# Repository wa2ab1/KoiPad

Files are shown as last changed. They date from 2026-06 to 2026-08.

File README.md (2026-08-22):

# KoiPad: External Numpad Companion with Rotary Encoder

KoiPad is an external numpad companion with a large rotary encoder, designed for a fun desk setup with fast numeric input.

Numpad


With its large 4 cm rotary encoder shaped like its eyeball and a USB-C cable inpsired by a fishing line, KoiPad adds a playful companion to your desk.

KoiPad was inspired by the koi shape from Hack Club's Fallout, and I wanted to turn that into something more unique than a typical macropad. When brainstorming case ideas, the ideas for the usb-c cable to be the fishing line at its mouth and the giant knob for its eye made the whole case concept click into place. With my current keyboard being a TKL layout, I also wanted a dedicated numpad which will help improve my number crunching.

## Features:

- 17-key standard numpad layout and num lock
- EC-11 rotary encoder for volume adjustment
- Seeeduino XIAO RP2040
- Standard MX switches with 2u PCB-mount stabilizers
- USB-C connection

Zine

## Case

3D print the top plate and bottom case separately, and secure them together using 5 mm M2 screws on the corners. The screws will need to be manually threaded into the bottom case.



### Painting:

The top plate is printed in one color only (red), with the outlines raised for easy brush painting. You'll need 3 colors (yellow, white, black) and red (optional). You can mix the paints for beige and red. First paint the yellow and beige areas, then go over the black outlines and white eye area for a clean finish. You may want to use masking tape to protect the sides of the outlines for a cleaner look. 



## PCB

The KoiPad utilizes standard keyboard switches with 2u PCB mounted stabilizers for the larger keys. After soldering your diodes and switches and snapping on the stabilizers, screw the pcb with 4mm standoffs of M2 size through the countersinks on the bottom of the case and the designated holes on the pcb. Screw these in before screwing on the top plate, and avoid rescrewing the top plate unless necessary to prevent stripping.

<p float="left">
  
  
  
</p>

## Schematic



## Firmware
The rotary encoder is configured to control system volume up/down, and the keypad includes Enter and Num Lock mappings. You may need to adjust these key codes if your environment handles these special keys differently.

### Libraries used: 
- Keypad
- Adafruit_TinyUSB

### Instructions:
- Find the board manager and look for "Seed SAMD Boards" or "Raspberry Pi Pico/RP2040/RP2350"
- Select XIAO RP2040 board in your COM ports
- Go to Tools -> USB Stack -> select "Adafruit TinyUSB"
- upload the koipad.ino file (hold the B/boot button on the xiao and plug it in, then click upload)

## Credits
3D placeholder/reference models used in renders were sourced from other creators. Final hardware uses real components.

Keycap, switches, stabilizers, standoffs, encoder, and Seeeduino XIAO footprints and 3d models from [ScottoKeebs](https://github.com/joe-scotto/scottokeebs)

[Screws](https://grabcad.com/library/metric-screws-from-m2-x-2-5-to-m2-x-20-1)

[USB-C cable](https://grabcad.com/library/usb-usb-cable-1)

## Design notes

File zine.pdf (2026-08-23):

# KKOOII

P

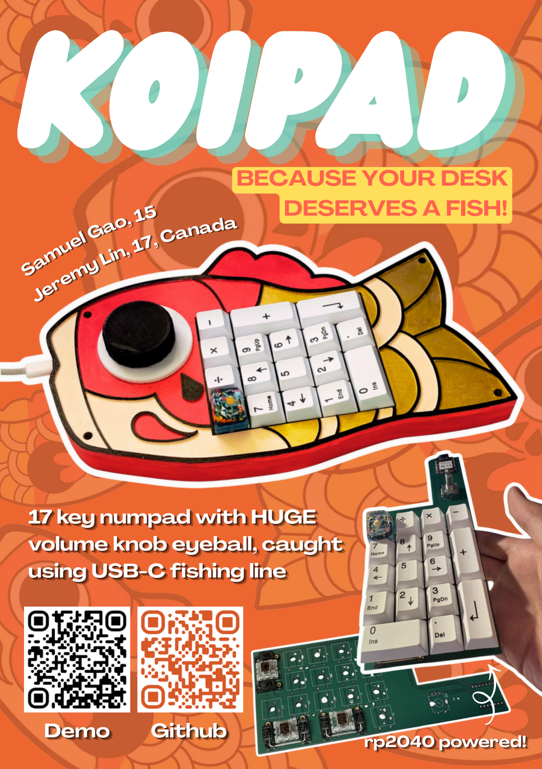
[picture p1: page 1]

111777kkkeeeyyynnnuuummmpppaaadddwwwiiittthhhHHHUUUGGGEEE vvvooollluuummmeeekkknnnooobbbeeeyyyeeebbbaaalll

lll,,,cccaaauuuggghhhttt
uuusssiiinnngggUUUSSSBBB---CCCfffiiissshhhiiinnngggllliiinnneee

### 17 key numpad with HUGE

volume knob eyeball, caught using USB-C fishing line

B

E

P

CAU

A

S

A

E YOU

D

R

D

DESK
DESERVES A FISH!
Jeremy Lin, 17, Canada
Jeremy Lin, 17, Canada

Jeremy Lin, 17, Canada

rrrppp222000444000pppooowwweeerrreeeddd!!!

Samuel Gao, 15
Samuel Gao, 15

Samuel Gao, 15

Demo GGGiiittthhhuuubbb

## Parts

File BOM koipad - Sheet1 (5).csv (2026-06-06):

Item | Description | Quantity | Per-Part Unit Price | Actual Item Price | URL | Actual Total Cost (13% Tax) | Theoretical Lowest Cost (with tax)
Keyboard Switches 20 Pack | Generic keyboard switches | 17 | 0.268 | 5.36 | https://www.aliexpress.com/item/1005011838889689.html | 125.3961 | 121.06594
M2 Screws 3 mm | Generic M2 screws | 5 | 0.0484 | 2.47 | https://www.aliexpress.com/item/1005002364568213.html
M2 Tapping Screws 5 mm | Must be self tapping screws | 4 | 0.645 | 2.58 | https://www.aliexpress.com/item/1005009140378459.html
Keycap set | Only need 17 key numpad keys | 1 | 10.47 | 10.47 | https://www.aliexpress.com/item/1005009153807344.html
4 mm M2 Hex Standoffs x50 | Female-Female Standoffs To support PCB above case | 5 | 0.02 | 5.91 | https://www.aliexpress.com/item/4000239735518.html
PCB mounted 2u Stabilizers x5 | PCB mount only Cherry style, 2u width | 3 | 3.62 | 10.85 | https://www.aliexpress.com/item/1005010788206824.html
EC11 Rotary Encoder | Encoder for knob | 1 | 2.57 | 2.57 | https://www.aliexpress.com/item/1005007644083514.html
USB-C Cable | Cable to connect to keyboard | 1 | 4.32 | 4.32 | https://www.aliexpress.com/item/1005004288047764.html
SEEED XIAO rp2040 | microcontroller | 1 | 16.75 | 16.75 | https://www.aliexpress.com/item/1005006593701624.html
3d Printed Case | 0.15 cents per g of filament | 1 | 16.58 | 16.58
3d Printed Top plate | 0.15 cents per g of filament | 1 | 6.24 | 6.24
3d printed knob | 0.15 cents per g of filament | 1 | 0.94 | 0.94
PCB | JLC PCB order ($9.60 for board, $19 shipping with coupon) | 1 | 25.93 | 25.93
Paint | Any paints will do, I have to buy a single color of yellow paint for 5 dollars | 1 | 5 | 5

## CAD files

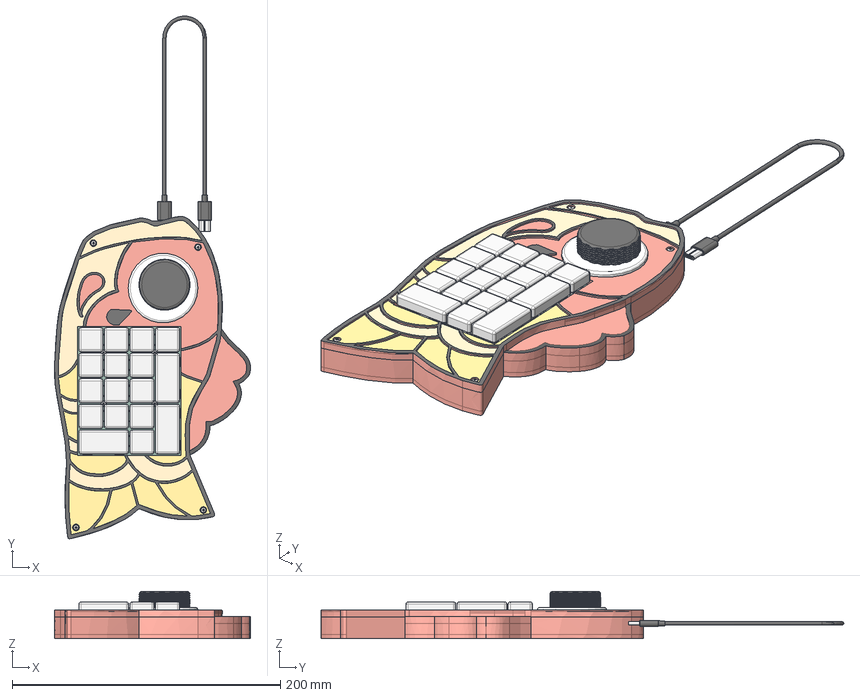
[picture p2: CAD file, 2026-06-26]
cad/Numpad.step
146.1 x 389.6 x 35.1 mm

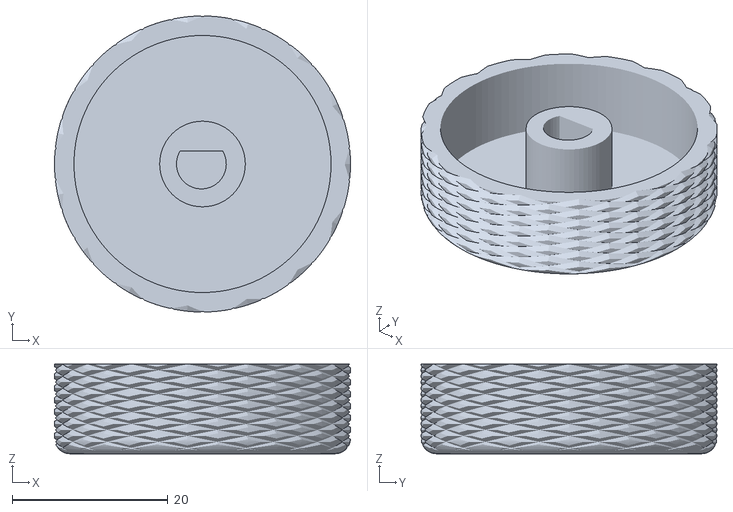
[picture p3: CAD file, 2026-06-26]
cad/Printables/knob.stl
38.0 x 38.0 x 11.5

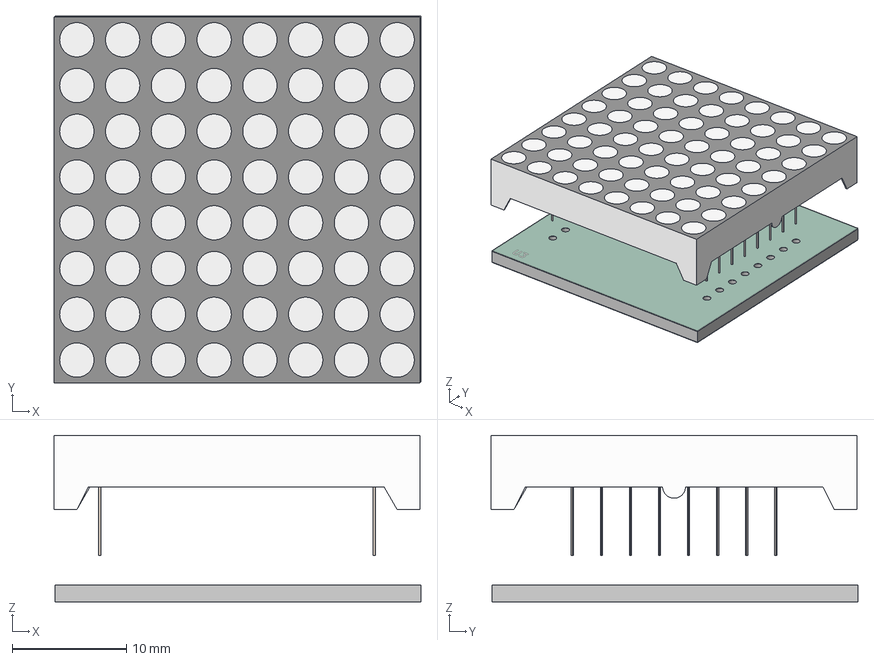
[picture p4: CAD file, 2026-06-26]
pcb/Racing_Hub/Racing_Hub.step
32.1 x 32.1 x 14.6 mm
1088-led_array
1088-shell
1088-lead x 16
1088-bottom-fill^1088
Racing_Hub_silkscreen
Racing_Hub_soldermask x 2
Racing_Hub_PCB

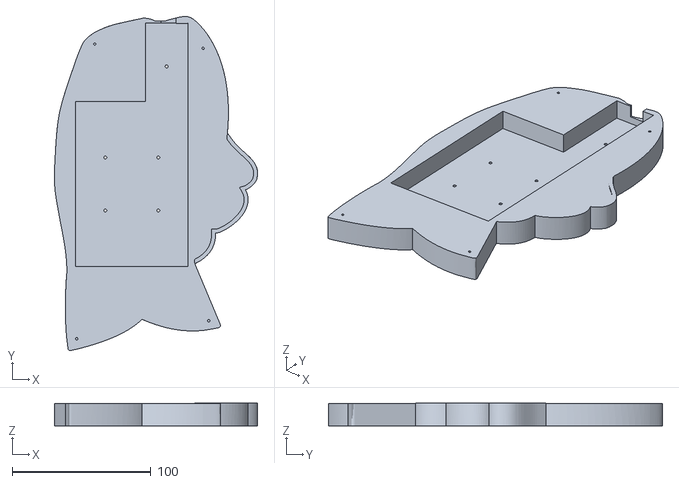
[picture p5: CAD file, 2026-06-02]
cad/Printables/bottom_plate.stl
146.1 x 240.3 x 16.5

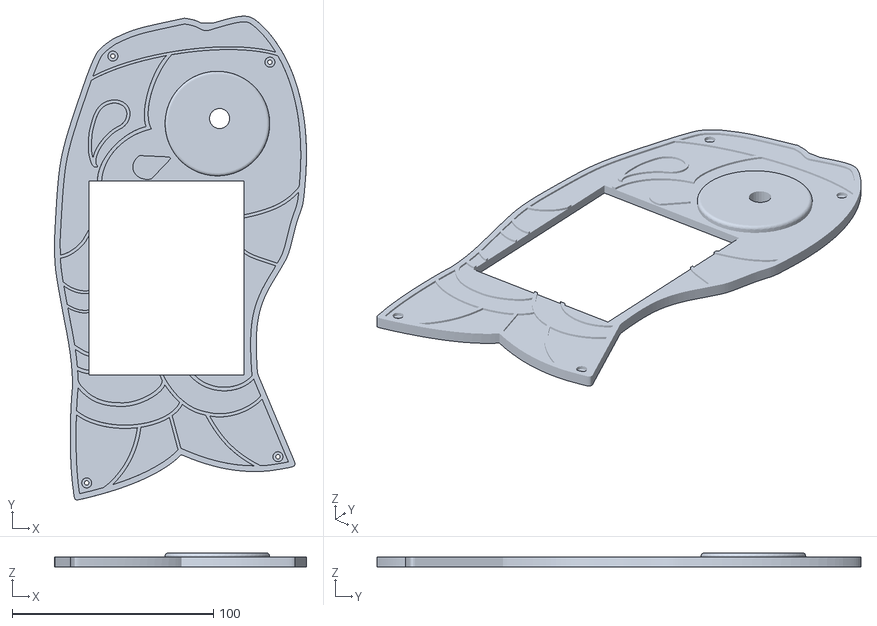
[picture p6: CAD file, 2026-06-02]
cad/Printables/top_plate.stl
125.2 x 240.3 x 7.00

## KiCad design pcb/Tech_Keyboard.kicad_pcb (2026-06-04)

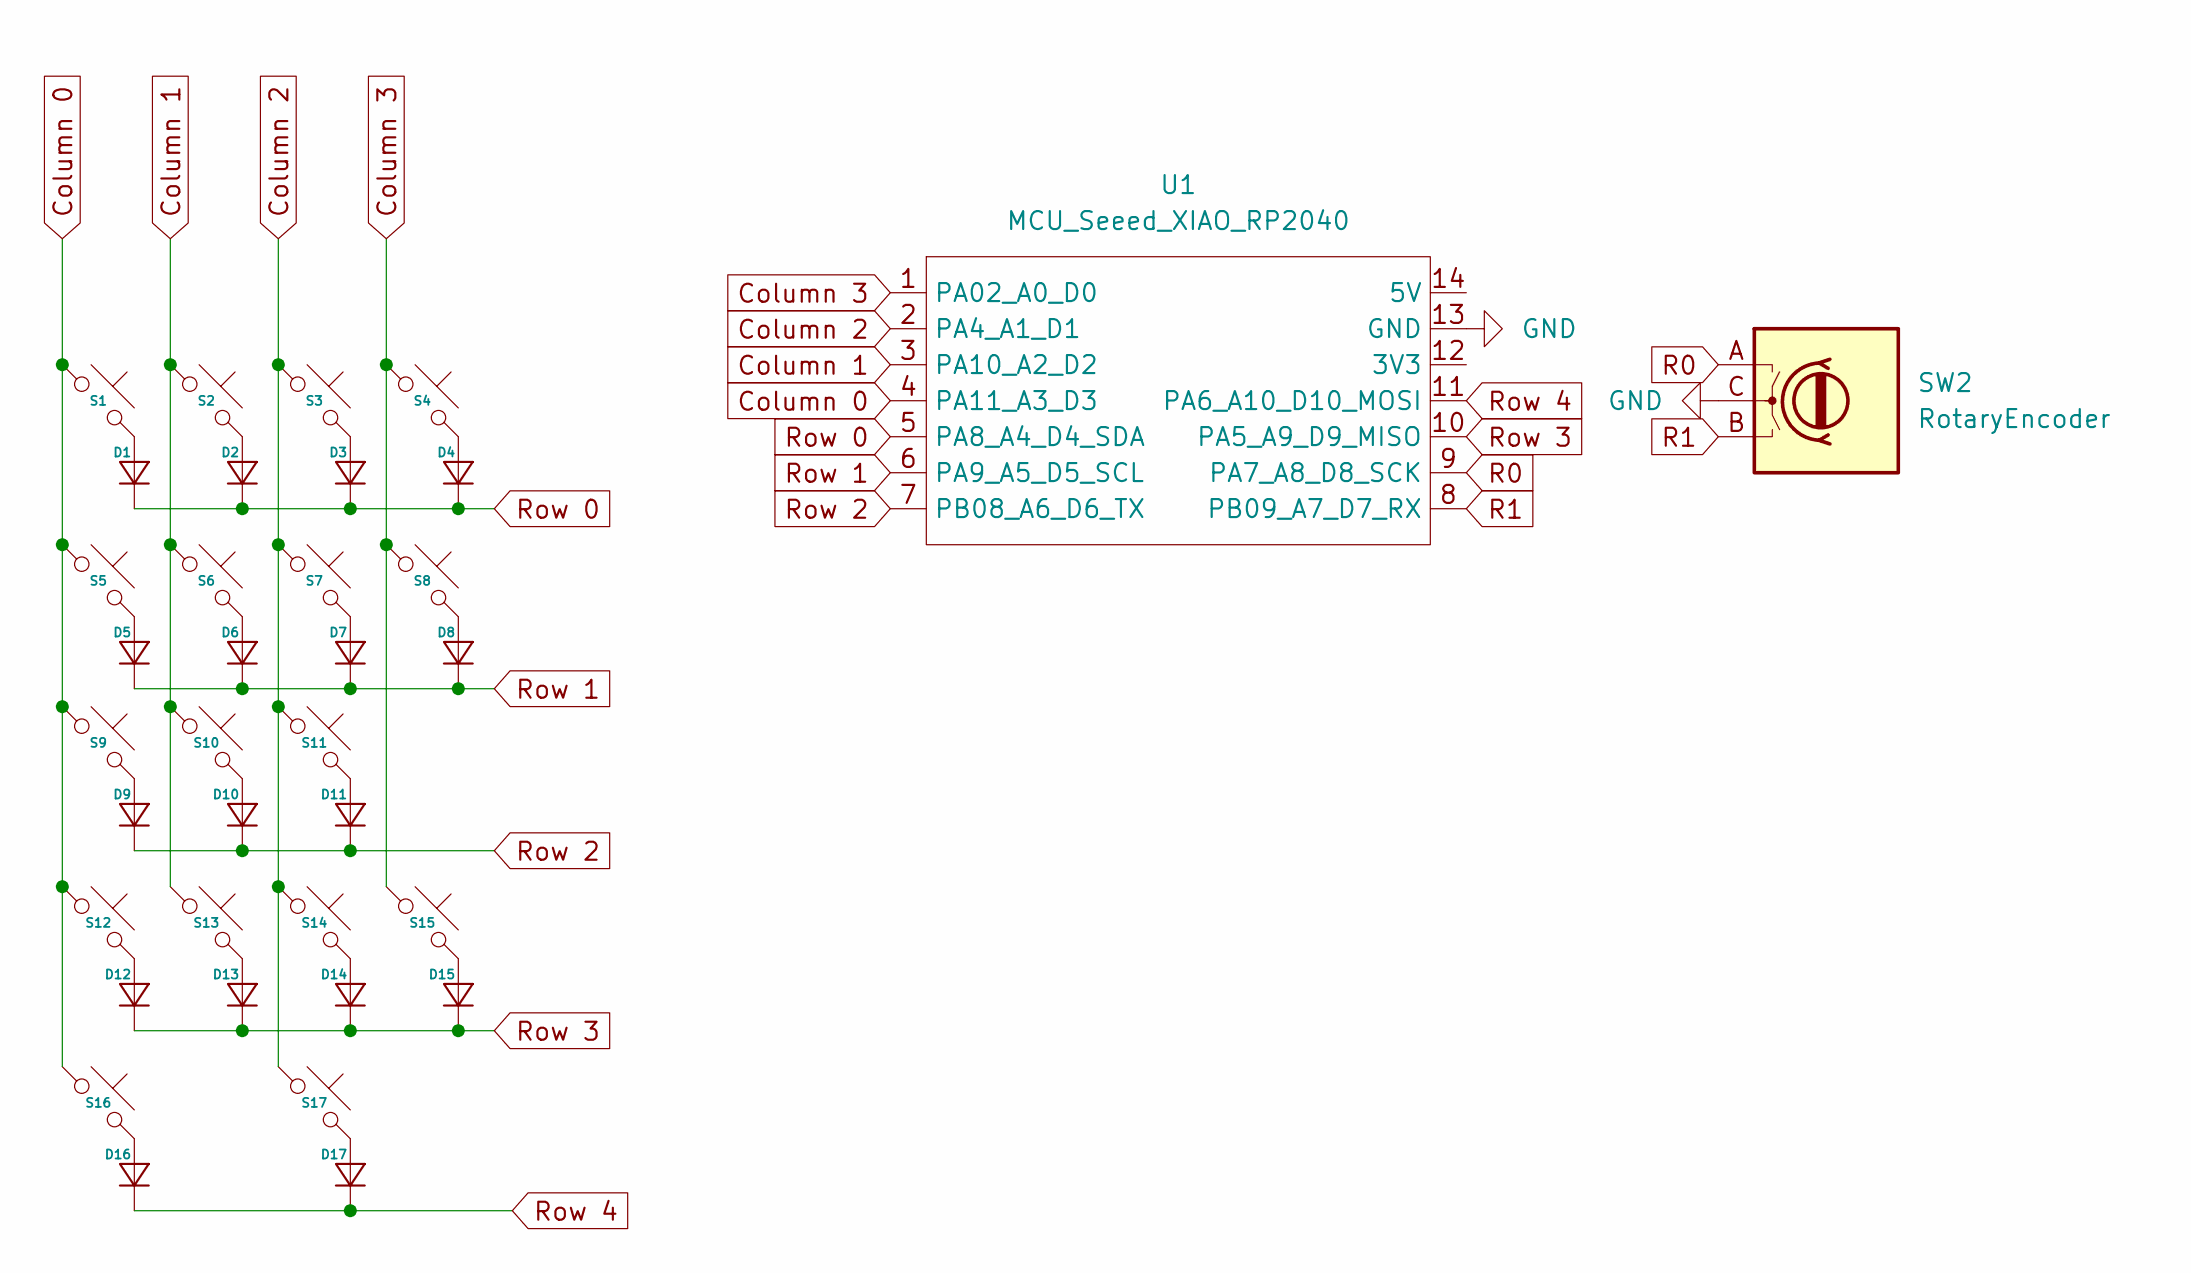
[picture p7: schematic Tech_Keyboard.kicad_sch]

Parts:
D1, D2, D3, D4, D5, D6, D7, D8, D9, D10, D11, D12, D13, D14, D15, D16, D17: (no value)
S1, S2, S3, S4, S5, S6, S7, S8, S9, S10, S11, S12, S13, S14, S15, S16, S17: (no value)
SW2: RotaryEncoder
U1: MCU_Seeed_XIAO_RP2040

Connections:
Column 0: S1.1, S5.1, S9.1, S12.1, S16.1, U1.4 (PA11_A3_D3)
Column 1: S2.1, S6.1, S10.1, S13.1, U1.3 (PA10_A2_D2)
Column 2: S3.1, S7.1, S11.1, S14.1, S17.1, U1.2 (PA4_A1_D1)
Column 3: S4.1, S8.1, S15.1, U1.1 (PA02_A0_D0)
GND: SW2.C, U1.13 (GND)
unnamed: D1.2 (A), S1.2
unnamed: D2.2 (A), S2.2
unnamed: D3.2 (A), S3.2
unnamed: D4.2 (A), S4.2
unnamed: D5.2 (A), S5.2
unnamed: D6.2 (A), S6.2
unnamed: D7.2 (A), S7.2
unnamed: D8.2 (A), S8.2
unnamed: D9.2 (A), S9.2
unnamed: D10.2 (A), S10.2
unnamed: D11.2 (A), S11.2
unnamed: D12.2 (A), S12.2
unnamed: D13.2 (A), S13.2
unnamed: D14.2 (A), S14.2
unnamed: D15.2 (A), S15.2
unnamed: D16.2 (A), S16.2
unnamed: D17.2 (A), S17.2
R0: SW2.A, U1.9 (PA7_A8_D8_SCK)
R1: SW2.B, U1.8 (PB09_A7_D7_RX)
Row 0: D1.1 (K), D2.1 (K), D3.1 (K), D4.1 (K), U1.5 (PA8_A4_D4_SDA)
Row 1: D5.1 (K), D6.1 (K), D7.1 (K), D8.1 (K), U1.6 (PA9_A5_D5_SCL)
Row 2: D9.1 (K), D10.1 (K), D11.1 (K), U1.7 (PB08_A6_D6_TX)
Row 3: D12.1 (K), D13.1 (K), D14.1 (K), D15.1 (K), U1.10 (PA5_A9_D9_MISO)
Row 4: D16.1 (K), D17.1 (K), U1.11 (PA6_A10_D10_MOSI)

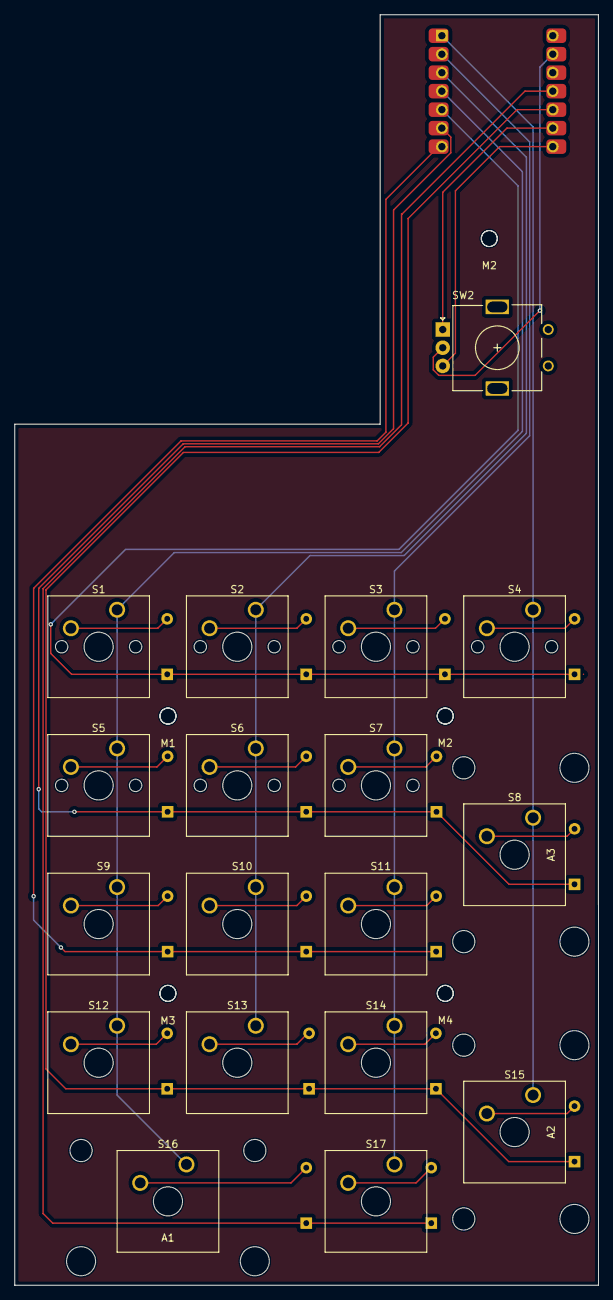
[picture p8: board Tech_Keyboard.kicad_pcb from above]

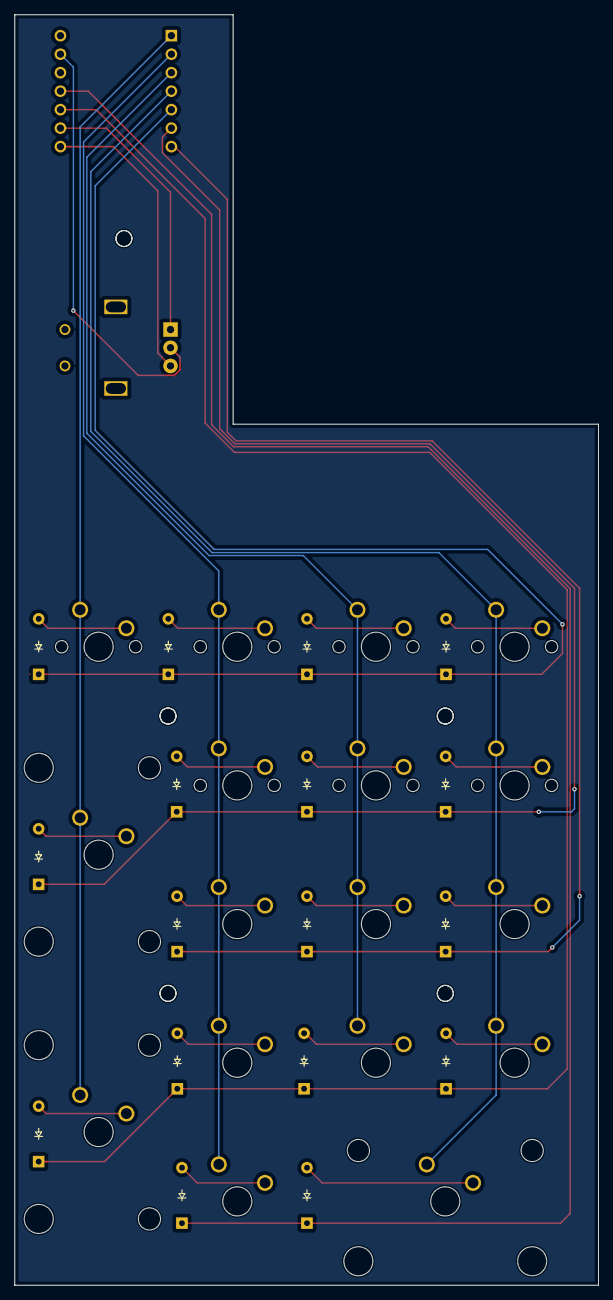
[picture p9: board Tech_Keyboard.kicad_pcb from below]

Board: 2 copper layers, 80.2 x 174.6 mm, 45 parts (17 on the bottom side), 29 nets.

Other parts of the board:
A1, A2, A3: Stabilizer_MX_2.00u
M1, M2, M2#2, M3, M4: MountingHole_2.2mm_M2
M3#2: Standoff_M2x4mm

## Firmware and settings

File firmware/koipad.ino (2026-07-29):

#include <Keypad.h>
#include <Adafruit_TinyUSB.h>
// Initialize the USB Consumer (Media) HID interface
Adafruit_USBD_HID usb_hid;

enum {
  RID_KEYBOARD = 1,
  RID_CONSUMER_CONTROL
};

uint8_t const desc_hid_report[] = {
  TUD_HID_REPORT_DESC_KEYBOARD( HID_REPORT_ID(RID_KEYBOARD) ),
  TUD_HID_REPORT_DESC_CONSUMER( HID_REPORT_ID(RID_CONSUMER_CONTROL) )
};

static hid_keyboard_report_t pressed_keys = { 0 };

// ---------- Keypad ----------
const byte ROWS = 4;
const byte COLS = 5;

uint8_t keys[ROWS][COLS] = {
  { HID_KEY_NUM_LOCK, HID_KEY_KEYPAD_7, HID_KEY_KEYPAD_4, HID_KEY_KEYPAD_1, HID_KEY_KEYPAD_0 },
  { HID_KEY_KEYPAD_DIVIDE, HID_KEY_KEYPAD_8, HID_KEY_KEYPAD_5, HID_KEY_KEYPAD_2, ' ' },
  { HID_KEY_KEYPAD_MULTIPLY, HID_KEY_KEYPAD_9, HID_KEY_KEYPAD_6, HID_KEY_KEYPAD_3, HID_KEY_KEYPAD_DECIMAL },
  { HID_KEY_KEYPAD_SUBTRACT, HID_KEY_KEYPAD_ADD, ' ', HID_KEY_KEYPAD_ENTER, ' ' },
};

byte columnPins[COLS] = { D4, D5, D6, D9, D10 };
byte rowPins[ROWS] = { D3, D2, D1, D0 };

Keypad customKeypad = Keypad(
  makeKeymap(keys),
  rowPins,
  columnPins,
  ROWS,
  COLS);

// ---------- Rotary encoder ----------
const int encoderPinA = D8; 
const int encoderPinB = D7;  

int lastA = 0;
int lastB = 0;

void setup() {

  Serial.begin(9600);

  // Encoder inputs with pull-ups
  pinMode(encoderPinA, INPUT_PULLUP);
  pinMode(encoderPinB, INPUT_PULLUP);

  lastA = digitalRead(encoderPinA);
  lastB = digitalRead(encoderPinB);

  usb_hid.setPollInterval(2);
  usb_hid.setReportDescriptor(desc_hid_report, sizeof(desc_hid_report));
  usb_hid.begin();
}

void loop() {

  if (customKeypad.getKeys()) {
    Serial.println("pressed");
    for (int i = 0; i < 10; i++) {
      if (customKeypad.key[i].stateChanged) 
      {
        if (customKeypad.key[i].kstate == PRESSED) 
        {
          
          uint8_t targetKey = customKeypad.key[i].kchar;

          for (int i = 0; i < 6; i++) 
          {
            if (pressed_keys.keycode[i] == 0) { // Find an empty slot
              pressed_keys.keycode[i] = targetKey; // Add the key
              Serial.println(targetKey);
              break;
            }
          }
          usb_hid.sendReport(RID_KEYBOARD, &pressed_keys, sizeof(pressed_keys));
        }         
        else if (customKeypad.key[i].kstate == RELEASED) 
        {
          uint8_t targetKey = customKeypad.key[i].kchar;

          for (int i = 0; i < 6; i++) 
          {
            if (pressed_keys.keycode[i] == targetKey) 
            {
              pressed_keys.keycode[i] = 0; // Clear ONLY this key slot
              break;
            }
          }
          usb_hid.sendReport(RID_KEYBOARD, &pressed_keys, sizeof(pressed_keys));

        }
      }
    }
  }

  // ----- Encoder handling -----
  int a = digitalRead(encoderPinA);
  int b = digitalRead(encoderPinB);

  // Only act when A changes; B tells direction
  if (a != lastA) {
    if (a == b) {
      // One direction: send e.g. Arrow Up
      uint16_t keycode = HID_USAGE_CONSUMER_VOLUME_INCREMENT;
      usb_hid.sendReport16(RID_CONSUMER_CONTROL, keycode);
      usb_hid.sendReport16(RID_CONSUMER_CONTROL, 0); 

    } else {
      // Other direction: send e.g. Arrow Down
      uint16_t keycode = HID_USAGE_CONSUMER_VOLUME_DECREMENT;
      usb_hid.sendReport16(RID_CONSUMER_CONTROL, keycode);
      usb_hid.sendReport16(RID_CONSUMER_CONTROL, 0); 
    }
  }
  lastA = a;
  lastB = b;
}

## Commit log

2026-05-20 updated to fish shape
    [Tech_Keyboard.kicad_pcb, Tech_Keyboard_PCB.f3d, Tech_Keyboard_PCB.step]
2026-05-30 Added 3d model and cleaned up files
    [Tech_Keyboard.kicad_pcb, Tech_Keyboard.kicad_sch, Tech_Keyboard_PCB.f3d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]
2026-05-30 update files gerber and f3z
    [Numpad_designators.csv, Numpad_positions.csv, Tech_Keyboard.kicad_pcb]
2026-05-30 added stl files
    [Bottom plate.stl, Top plate.stl, knob knurled.stl]
2026-05-30 Create knob upside down.stl
    [knob upside down.stl]
2026-06-02 cleaned up git
    [BOM koipad.csv, Bottom plate.stl, Numpad_bom.csv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]
2026-06-02 extra git formatting
    [BOM.csv, Tech_Keyboard.kicad_pcb, Tech_Keyboard.kicad_sch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]
2026-06-02 updated cad files
2026-06-04 update knob direction
    [Tech_Keyboard.kicad_pcb, knob.stl]
2026-06-05 update bom
    [BOM.csv]
2026-06-05 change bom name
    [BOM.csv]
2026-06-05 fixing bom again
    [BOM koipad - Sheet1 (3).csv]
2026-06-05 change file nmae
    [BOM.csv]
2026-06-05 new bom again
    [BOM koipad - Sheet1 (4).csv]
2026-06-05 rename bom
    [BOM.csv]
2026-06-06 update bom 1
    [BOM koipad - Sheet1 (5).csv]
2026-06-06 bom change 2
    [BOM.csv]
2026-06-26 update knob
    [Numpad.step, Racing_Hub.kicad_pcb, Racing_Hub.kicad_sch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]
